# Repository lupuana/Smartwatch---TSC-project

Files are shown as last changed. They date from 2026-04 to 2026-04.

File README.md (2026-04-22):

# Smartwatch — TSC Project

> A custom-designed smartwatch based on the **Nordic nRF52840** SoC, featuring an e-paper display interface, haptic feedback, accelerometer-based motion sensing, LiPo battery management, and Bluetooth Low Energy connectivity. The PCB measures **46 × 35 mm** with rounded corners and is designed to fit inside a 3D-printed enclosure.

---

## Table of Contents

1. [Block Diagram](#block-diagram)
2. [Bill of Materials (BOM)](#bill-of-materials-bom)
3. [Hardware Description](#hardware-description)
4. [nRF52840 Pin Assignments](#nrf52840-pin-assignments)
5. [PCB Images](#pcb-images)
6. [Mechanical / Enclosure](#mechanical--enclosure)
7. [Design Notes](#design-notes)

---

## Block Diagram

```
                          ┌───────────────────────────────────────────────────────────────────┐
                          │                        nRF52840 (U1)                              │
                          │   ARM Cortex-M4F @ 64 MHz · 1 MB Flash · 256 KB RAM · BLE 5.0   │
                          └──┬──────────┬──────────┬──────────┬──────────┬──────────┬────────┘
                             │          │          │          │          │          │
                    SPI Bus  │   I2C Bus│  I2C Bus │  GPIO    │  SWD     │  GPIO    │  GPIO
                             │          │          │          │          │          │
               ┌─────────────▼──┐  ┌───▼────┐ ┌──▼──────┐  │   ┌──────▼──────┐  ┌▼───────┐
               │  E-Paper (EPD) │  │ BMA423 │ │DRV2605  │  │   │ TC2030-IDC  │  │ 3× SW  │
               │  24-pin FPC    │  │ Accel. │ │ Haptic  │  │   │ SWD Debug   │  │(UP/DN/ │
               │  (J1 Molex)    │  │ (IC3)  │ │ Driver  │  │   │ Connector   │  │  ENT)  │
               └────────────────┘  └────────┘ │ (IC2)   │  │   └─────────────┘  └────────┘
                                              └─────────┘  │
                                                           │
                          ┌────────────────────────────────┼──────────────────────────────────┐
                          │              Power System       │                                  │
                          │                                 │                                  │
               ┌──────────▼──┐   ┌──────────┐   ┌────────▼──────┐   ┌──────────────────┐   │
               │ USB Type-C  │   │BQ25180   │   │  MAX17048     │   │   RT6160AWSC     │   │
               │  (J4)       ├──►│ LiPo     │   │  Fuel Gauge   │   │  Buck-Boost Reg. │   │
               │ + ESD D3    │   │ Charger  │   │  (U3) I2C     │   │  (IC9) I2C       │   │
               └─────────────┘   │ (IC1)    │   └───────────────┘   └──────────────────┘   │
                                 └────┬─────┘                                                │
                                      │ VBAT                                                 │
                                 ┌────▼─────┐                                                │
                                 │  LiPo    │                                                │
                                 │ Battery  │                                                │
                                 │ (J3 pad) │                                                │
                                 └──────────┘                                                │
                                                                                             │
               ┌──────────────────────────────────────────────────────────────────┐          │
               │                    RF Front-End                                   │          │
               │  32 MHz XTAL (X1) · 32.768 kHz XTAL (X2) · ANT1 2.45 GHz       │◄─────────┘
               │  Matching network: L1 3.9 nH · L2 10 µH · L3 15 nH             │
               └──────────────────────────────────────────────────────────────────┘
```

---

## Bill of Materials (BOM)

> Procurement links point to **JLCPCB Parts** where available; datasheets linked to official manufacturer sources.

| Ref(s) | Qty | Value / Part | Description | Package | JLCPCB / Buy Link | Datasheet |
|---|---|---|---|---|---|---|
| U1 | 1 | NRF52840-QIAA | Nordic nRF52840 SoC — main MCU, BLE 5.0, ARM Cortex-M4F | AQFN-73 (aQFN50) | [JLCPCB C190794](https://jlcpcb.com/partdetail/NordicSemiconductor-NRF52840_QIAA/C190794) | [Datasheet](https://infocenter.nordicsemi.com/pdf/nRF52840_PS_v1.7.pdf) |
| IC1 | 1 | BQ25180YBGR | 1-cell LiPo charger, I²C programmable, 1 A | 8-DSBGA (1.6×1.1 mm) | [JLCPCB C2828062](https://jlcpcb.com/partdetail/TexasInstruments-BQ25180YBGR/C2828062) | [Datasheet](https://www.ti.com/lit/ds/symlink/bq25180.pdf) |
| IC2 | 1 | DRV2605YZFR | Haptic driver for ERM/LRA motors, I²C, built-in waveform library | 9-BGA (1.44×1.44 mm) | [JLCPCB C529659](https://jlcpcb.com/partdetail/TexasInstruments-DRV2605YZFR/C529659) | [Datasheet](https://www.ti.com/lit/ds/symlink/drv2605.pdf) |
| IC3 | 1 | BMA423 | Triaxial 12-bit accelerometer, step counter, I²C/SPI | LGA-12 (2×2 mm) | [JLCPCB C332973](https://jlcpcb.com/partdetail/BoschSensortec-BMA423/C332973) | [Datasheet](https://www.bosch-sensortec.com/media/boschsensortec/downloads/datasheets/bst-bma423-ds000.pdf) |
| IC9 | 1 | RT6160AWSC | Buck-boost DC-DC converter, I²C, 15-pin WL-CSP | BGA-15 (1.4×2.3 mm) | [JLCPCB C2834980](https://jlcpcb.com/partdetail/Richtek-RT6160AWSC/C2834980) | [Datasheet](https://www.richtek.com/assets/product_file/RT6160A/DS6160A-00.pdf) |
| U3 | 1 | MAX17048G+T10 | 1-cell/2-cell LiPo fuel gauge, I²C ModelGauge | TDFN-8 (2×2 mm) | [JLCPCB C368489](https://jlcpcb.com/partdetail/MaximIntegrated-MAX17048G_T10/C368489) | [Datasheet](https://www.analog.com/media/en/technical-documentation/data-sheets/MAX17048-MAX17049.pdf) |
| J1 | 1 | 503480-2400 | Molex 0.5 mm FPC/FFC 24-circuit RA SMT dual-contact connector (EPD) | — | [Mouser 538-503480-2400](https://www.mouser.com/ProductDetail/Molex/503480-2400) | [Datasheet](https://www.molex.com/en-us/products/part-detail/5034802400) |
| J2 | 1 | TC2030-IDC | Tag-Connect 6-pin SWD programming/debug header (no-drill) | TC2030IDC | [Tag-Connect](https://www.tag-connect.com/product/tc2030-idc-nl) | [Info](https://www.tag-connect.com/wp-content/uploads/bsk-pdf-manager/TC2030-IDC-NL_Datasheet_8.pdf) |
| J4 | 1 | KH-TYPE-C-16P | USB Type-C 16-pin SMT receptacle | — | [LCSC C2832](https://www.lcsc.com/product-detail/USB-Connectors_Kinghelm-KH-TYPE-C-16P_C2832.html) | [Datasheet](https://www.kinghelm.com.cn/product/kh-type-c-16p.html) |
| ANT1 | 1 | 2450AT18B100E | 2.45 GHz chip antenna for BLE | 3216 (1.4 mm H) | [JLCPCB C341461](https://jlcpcb.com/partdetail/JohansonTechnology-2450AT18B100E/C341461) | [Datasheet](https://www.johansontechnology.com/datasheets/2450AT18B100E/2450AT18B100E.pdf) |
| D3 | 1 | USBLC6-2SC6Y | USB ESD protection TVS diode array | SOT-23-6 | [JLCPCB C2687116](https://jlcpcb.com/partdetail/STMicroelectronics-USBLC6_2SC6Y/C2687116) | [Datasheet](https://www.st.com/resource/en/datasheet/usblc6-2.pdf) |
| D2, D4, D5 | 3 | MBR0530 | Schottky diode, 30 V / 500 mA | SOD-123 | [JLCPCB C424037](https://jlcpcb.com/partdetail/OnSemiconductor-MBR0530/C424037) | [Datasheet](https://www.onsemi.com/pdf/datasheet/mbr0530-d.pdf) |
| Q3 | 1 | SI1308EDL-T1-GE3 | N-channel MOSFET, 30 V / 1.5 A | SC-70 (SOT-323) | [JLCPCB C145826](https://jlcpcb.com/partdetail/VishayIntertech-Si1308EDL_T1_GE3/C145826) | [Datasheet](https://www.vishay.com/docs/63533/si1308edl.pdf) |
| DMG2305UX-7 | 1 | DMG2305UX-7 | P-channel MOSFET, 20 V / 4.2 A | SOT-23 | [JLCPCB C145702](https://jlcpcb.com/partdetail/Diodes-DMG2305UX7/C145702) | [Datasheet](https://www.diodes.com/assets/Datasheets/DMG2305UX.pdf) |
| SW_UP, SW_DN, SW_ENT | 3 | EVP-AKE31A | Panasonic SMD tactile push-button | — | [Digi-Key P123437TR-ND](https://www.digikey.com/en/products/detail/panasonic-electronic-components/EVP-AKE31A/3071225) | [Datasheet](https://industrial.panasonic.com/cdbs/www-data/pdf/ATV0000/ATV0000CE22.pdf) |
| X1 | 1 | 32 MHz crystal | RF clock for nRF52840 BLE | 2016 (2.0×1.6 mm) | [JLCPCB C9003](https://jlcpcb.com/partdetail/9003-CX2016DB32000D0GEJCC/C9003) | [Nordic recommended crystals](https://infocenter.nordicsemi.com/topic/ps_nrf52840/chapters/radio/doc/radio.html) |
| X2 | 1 | 32.768 kHz crystal | RTC/low-power clock | 3215 (3.2×1.5 mm) | [JLCPCB C32346](https://jlcpcb.com/partdetail/Hosonic-E3SB32E002400TR/C32346) | [Nordic RTC guidance](https://infocenter.nordicsemi.com/topic/ps_nrf52840/chapters/clock/doc/clock.html) |
| L1 | 1 | 3.9 nH inductor | RF matching, 0402 | 0402 | [JLCPCB C70268](https://jlcpcb.com/partdetail/70268-CL05NPC3N9BANC/C70268) | — |
| L2 | 1 | 10 µH inductor | BLE DC supply filter, 0402 | 0402 | [JLCPCB C1046](https://jlcpcb.com/partdetail/1046-CL31A226KAHNNNE/C1046) | — |
| L3 | 1 | 15 nH inductor | RF matching, 0402 | 0402 | [JLCPCB C70268](https://jlcpcb.com/partdetail/70268-CL05NPC3N9BANC/C70268) | — |
| L5 | 1 | 744043680 (68 µH) | Würth EP power inductor for buck-boost | 4828 (WE-TPC) | [JLCPCB C408386](https://jlcpcb.com/partdetail/WurthElektronik-744043680/C408386) | [Datasheet](https://www.we-online.com/en/components/products/WE-TPC#744043680) |
| L7 | 1 | FTC252012SR47MBCA | 0.47 µH power inductor for battery charger | MLP2016 (2×1.6 mm) | [JLCPCB C5832368](https://jlcpcb.com/partdetail/6763488-FTC252012SR47MBCA/C5832368) | [Datasheet](https://product.tdk.com/en/search/inductor/inductor/smd/info?part_no=FTC252012SR47MBCA) |
| C1–C43, EPD_Cx | ~50 | Various caps | Decoupling / bypass / filter (1 pF – 22 µF) | 0201, 0402 | JLCPCB standard passives | — |
| R1–R18, R_* | ~20 | Various resistors | Pull-ups, current-sense, type-select (0 Ω – 10 kΩ) | 0201 | JLCPCB standard passives | — |
| SJ1 | 1 | Solder jumper | EPD power rail selection | — | — | — |
| TP_* | 14 | Test pads | GND, 3V3, VBAT, SDA, SCL, SWDCLK, SWDIO, SWO, RESET, etc. | TP20R | — | — |

---

## Hardware Description

### 1. Microcontroller — Nordic nRF52840 (U1)

The nRF52840 is the heart of the project. It is an ARM Cortex-M4F SoC running at up to 64 MHz, with 1 MB of internal Flash, 256 KB RAM, and an integrated BLE 5.0 + 802.15.4 radio. It was chosen for its best-in-class sleep current (~2 µA in System OFF with RAM retention), its rich peripheral set (SPI, I²C, UART, USB, SWD), and its support for the Nordic SDK / Zephyr RTOS.

The chip is clocked by two external crystals: a 32 MHz crystal (X1) used as the main RF clock, and a 32.768 kHz crystal (X2) used by the RTC for low-power timekeeping. The RF matching network (L1 3.9 nH, L3 15 nH, and associated capacitors) connects the chip's antenna output to the chip antenna ANT1.

### 2. E-Paper Display Interface

The e-paper display (EPD) connects through a **Molex 503480-2400** 24-pin 0.5 mm pitch FPC right-angle connector (J1). The display is driven over **SPI** from the nRF52840. A dedicated group of capacitors (EPD_C1–EPD_C12, all 1 µF/50 V in 0402) and a filter capacitor (EPD_C5, 100 nF/50 V) provide local bypass for the EPD power rails. A solder jumper (SJ1) allows selecting the EPD supply source. The P-channel MOSFET (DMG2305UX-7) acts as a load switch to cut EPD power when the display is not being updated, minimising average current draw.

> **Note:** The display module itself is not included in this design iteration — the FPC connector and power circuitry are present and ready for integration.

### 3. Power Management

Power management is implemented with a three-chip solution:

**BQ25180YBGR (IC1) — LiPo Charger.** This Texas Instruments single-cell charger accepts 5 V from the USB Type-C port and charges a LiPo battery at up to 1 A. Charge current is configured via a current-sense resistor (R1_EP_DR, 0.47 Ω). The charger communicates with the nRF52840 over I²C for status reporting and charge parameter programming. An inductor L7 (0.47 µH) is used in the switch-mode charging path. Schottky diodes D2, D4, D5 (MBR0530) protect against reverse current conditions.

**MAX17048G+T10 (U3) — Fuel Gauge.** This Analog Devices ModelGauge IC measures the battery state-of-charge using a voltage-based algorithm, eliminating the need for a series current-sense resistor. It communicates over I²C and draws only 3 µA during normal operation, making it suitable for always-on battery monitoring.

**RT6160AWSC (IC9) — Buck-Boost Regulator.** This Richtek I²C-programmable buck-boost converter maintains a stable 3.3 V output rail (VREG) from the LiPo battery voltage, which can range from ~3.0 V (discharged) to 4.2 V (fully charged). The output voltage is dynamically adjustable via I²C, and the converter supports up to ~600 mA output current. The large 68 µH inductor L5 (Würth 744043680) is used in the power conversion path.

**USB Protection.** The USB Type-C port (J4) is protected by a USBLC6-2SC6Y (D3) ESD TVS diode array in SOT-23-6, clamping transients to a safe level before they reach the nRF52840's USB pins. The USB CC lines carry 5.1 kΩ resistors (R1_USB, R2_USB) for USB-C sink identification.

### 4. Accelerometer — BMA423 (IC3)

The Bosch BMA423 is a triaxial 12-bit accelerometer with hardware step counting, activity recognition (walk, run, still), and wrist-tilt gesture detection — all computed on-chip, so the main MCU can remain in deep sleep. It connects to the nRF52840 over **I²C**. Pull-up resistors (R5, R7 — 10 kΩ each) are placed on the SDA and SCL lines. The device draws only 14 µA in low-power mode at 25 Hz ODR.

### 5. Haptic Driver — DRV2605YZFR (IC2)

The Texas Instruments DRV2605 drives an ERM (eccentric rotating mass) or LRA (linear resonant actuator) vibration motor. It contains a library of 123 pre-programmed haptic waveforms accessible over **I²C**, allowing the firmware to trigger complex tactile patterns with a single register write. Pull-up resistors R17 and R18 (3.3 kΩ each) are provided on the I²C lines shared with the haptic driver.

### 6. Navigation Buttons

Three Panasonic EVP-AKE31A SMD tactile push-buttons are placed along the bottom edge of the PCB (SW_UP, SW_DN, SW_ENT), corresponding to UP, DOWN, and ENTER/SELECT functions. Each button connects to a GPIO pin of the nRF52840 with 10 kΩ pull-up resistors (R5, R7, R8). The nRF52840's internal sense and GPIO interrupt mechanisms enable wake-from-sleep on button press.

### 7. BLE Antenna

The 2.45 GHz chip antenna 2450AT18B100E from Johanson Technology (ANT1) is a compact 3.2×1.6 mm ceramic antenna placed at the top edge of the PCB, away from ground pours to maximise radiation efficiency. The matching network (L1, L3, and associated capacitors C3, C4) is tuned for 50 Ω impedance at 2.45 GHz as recommended by the nRF52840 reference design.

### 8. Debug / Programming Interface

A Tag-Connect TC2030-IDC footprint (J2) provides a 6-pin no-drill SWD debug interface, exposing SWDCLK, SWDIO, SWO, RESET, GND, and VCC. Dedicated test points (TP_SWDCLK, TP_SWDIO, TP_SWO, TP_RESET) are accessible on the PCB for bench probing.

### 9. Power Consumption Estimates

| Mode | Dominant Consumer | Estimated Current |
|---|---|---|
| BLE advertising (1 Hz) | nRF52840 radio | ~20 µA average |
| BLE connected (15 ms CI) | nRF52840 radio | ~5–8 mA peak, ~500 µA avg |
| EPD full refresh | EPD + nRF52840 | ~20 mA peak, ~2 s |
| Accelerometer step count only | BMA423 | ~14 µA |
| Haptic pulse (100 ms) | DRV2605 + motor | ~50–120 mA peak |
| System OFF (deep sleep) | nRF52840, fuel gauge | ~5–8 µA |

With a typical 150–300 mAh LiPo battery and BLE advertising once per second, an estimated **5–10 days** of battery life is achievable when the EPD is updated only a few times per day.

---

## nRF52840 Pin Assignments

| nRF52840 Pin | Signal Name | Connected To | Interface | Notes |
|---|---|---|---|---|
| P0.02 | AREF | ADC reference | Analog | Optional ADC reference |
| P0.04 / AIN2 | BATTERY_ADC | VBAT resistor divider | ADC | Battery voltage sense backup |
| P0.06 | UART_TX | Debug UART | UART | Optional logging |
| P0.08 | UART_RX | Debug UART | UART | Optional logging |
| P0.11 | SW_UP | SW_UP button | GPIO IN | Active-low, pull-up 10 kΩ |
| P0.12 | SW_DN | SW_DN button | GPIO IN | Active-low, pull-up 10 kΩ |
| P0.13 | SW_ENT | SW_ENT button | GPIO IN | Active-low, pull-up 10 kΩ |
| P0.14 / SDA | I2C_SDA | BMA423, DRV2605, BQ25180, MAX17048, RT6160 | I²C | 10 kΩ pull-up to 3V3 |
| P0.15 / SCL | I2C_SCL | BMA423, DRV2605, BQ25180, MAX17048, RT6160 | I²C | 10 kΩ pull-up to 3V3 |
| P0.16 | EPD_MOSI | EPD SPI data | SPI | — |
| P0.17 | EPD_SCK | EPD SPI clock | SPI | — |
| P0.18 / RESET | nRESET | TP_RESET, TC2030 | Reset | Active-low hardware reset |
| P0.19 | EPD_CS | EPD chip select | SPI / GPIO | Active-low |
| P0.20 | EPD_DC | EPD data/command select | GPIO | — |
| P0.21 | EPD_RST | EPD hardware reset | GPIO | Active-low |
| P0.22 | EPD_BUSY | EPD busy signal | GPIO IN | Input, pulled low by EPD |
| P0.23 | EPD_PWR_EN | DMG2305UX-7 gate | GPIO | Controls EPD power switch |
| P0.26 | VIB_EN | DRV2605 IN/TRIG | GPIO | Haptic trigger |
| P0.31 / AIN7 | BAT_SENSE | MAX17048 / VBAT | ADC / I²C | Fuel gauge interrupt line |
| P1.00 | SWO | TC2030-IDC pin 6 | SWD | Trace output |
| SWDIO | SWDIO | TC2030-IDC pin 2, TP_SWDIO | SWD | — |
| SWDCLK | SWDCLK | TC2030-IDC pin 4, TP_SWDCLK | SWD | — |
| GND | GND | Common ground, TP_GND | — | Multiple ground test points |
| VDD | 3V3 (from RT6160) | Decoupling caps C5–C19 etc. | Power | Per Nordic reference layout |
| VDDMAIN | 3V3 | Bulk decoupling | Power | — |
| XC1 / XC2 | 32 MHz XTAL | X1 | XTAL | Pins per nRF52840 datasheet |
| XL1 / XL2 | 32.768 kHz XTAL | X2 | XTAL | Pins per nRF52840 datasheet |
| ANT | RF output | L1 → ANT1 | RF | Via matching network |

---

## PCB Images

### 2D Layout — Top Layer

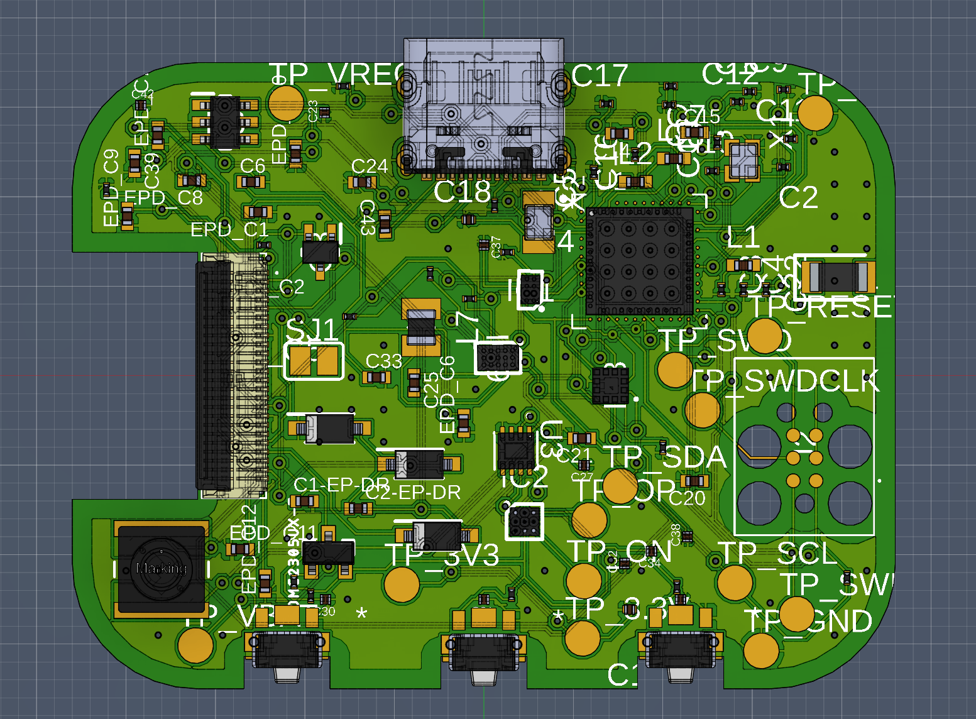
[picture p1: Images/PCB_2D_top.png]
PCB Top Layer


### 2D Layout — Bottom Layer

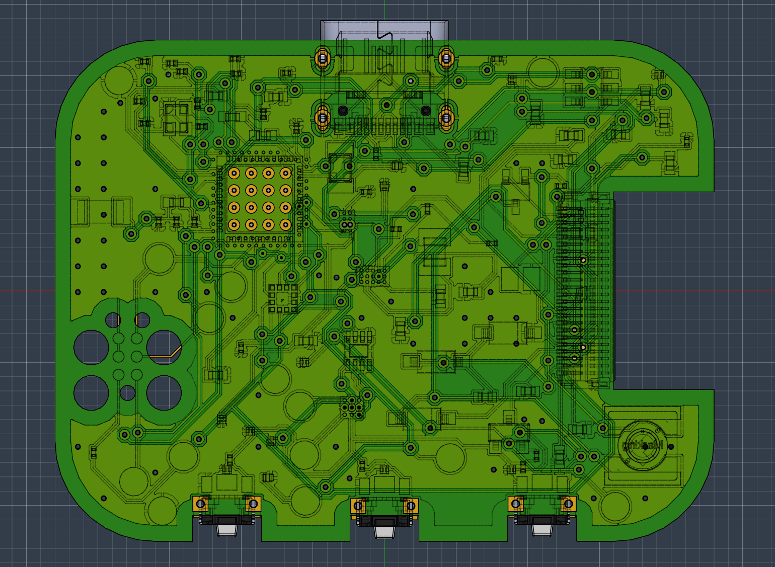
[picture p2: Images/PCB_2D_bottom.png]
PCB Bottom Layer


### 2D Layout — Combined (Top + Bottom)

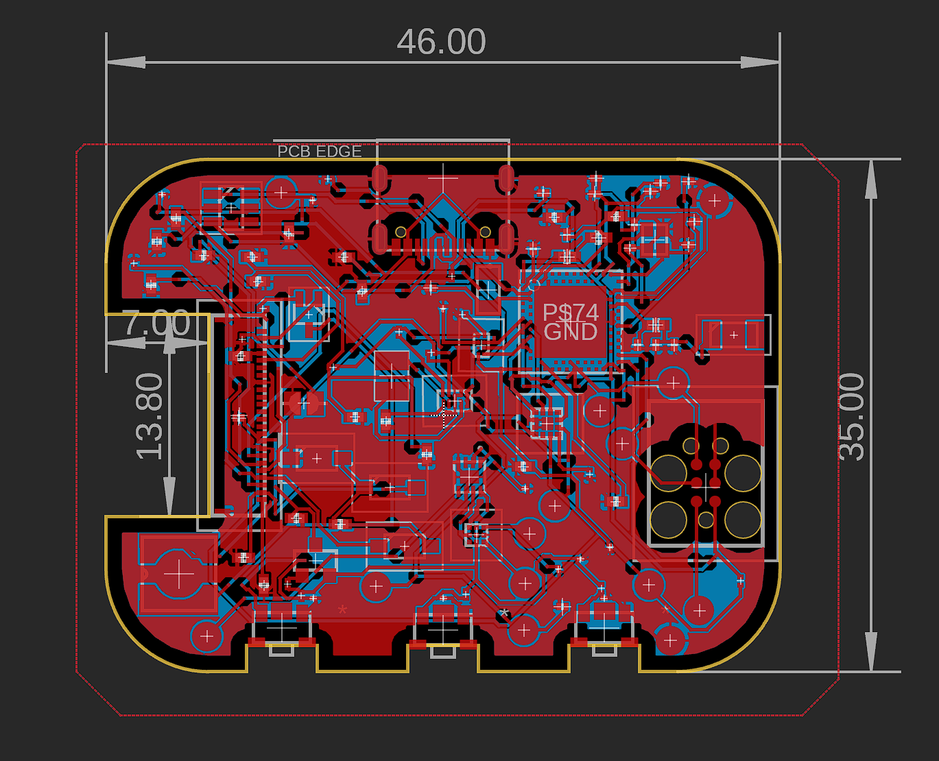
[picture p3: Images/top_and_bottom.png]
PCB Top and Bottom


### 3D Render — Top

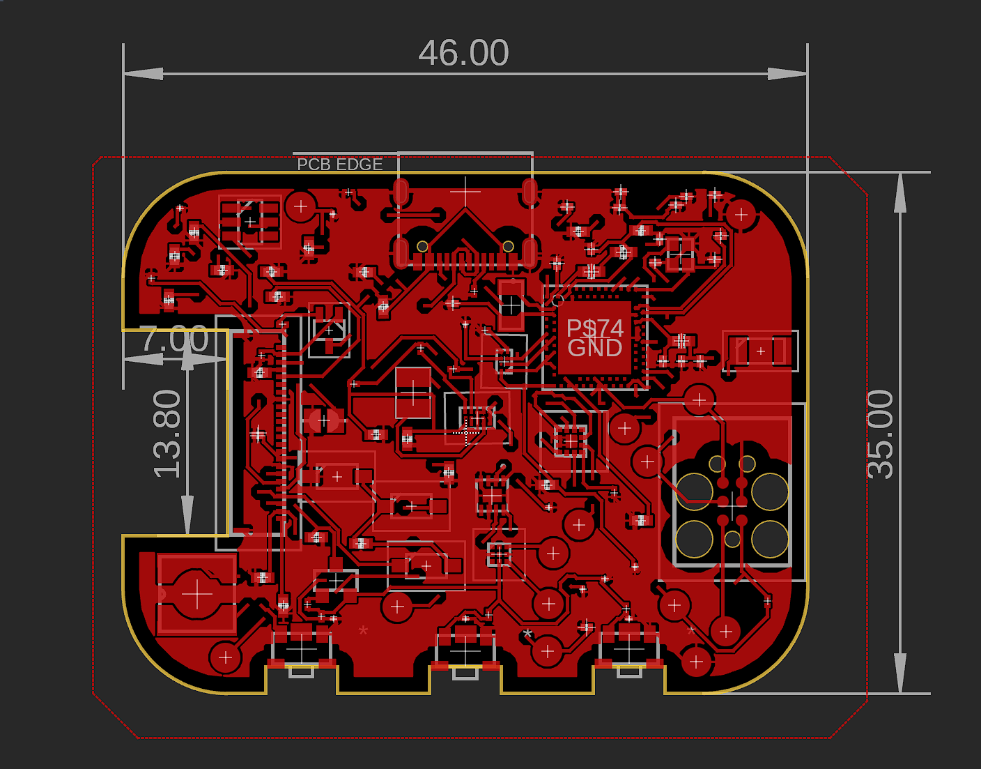
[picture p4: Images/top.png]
3D Render Top


### 3D Render — Bottom

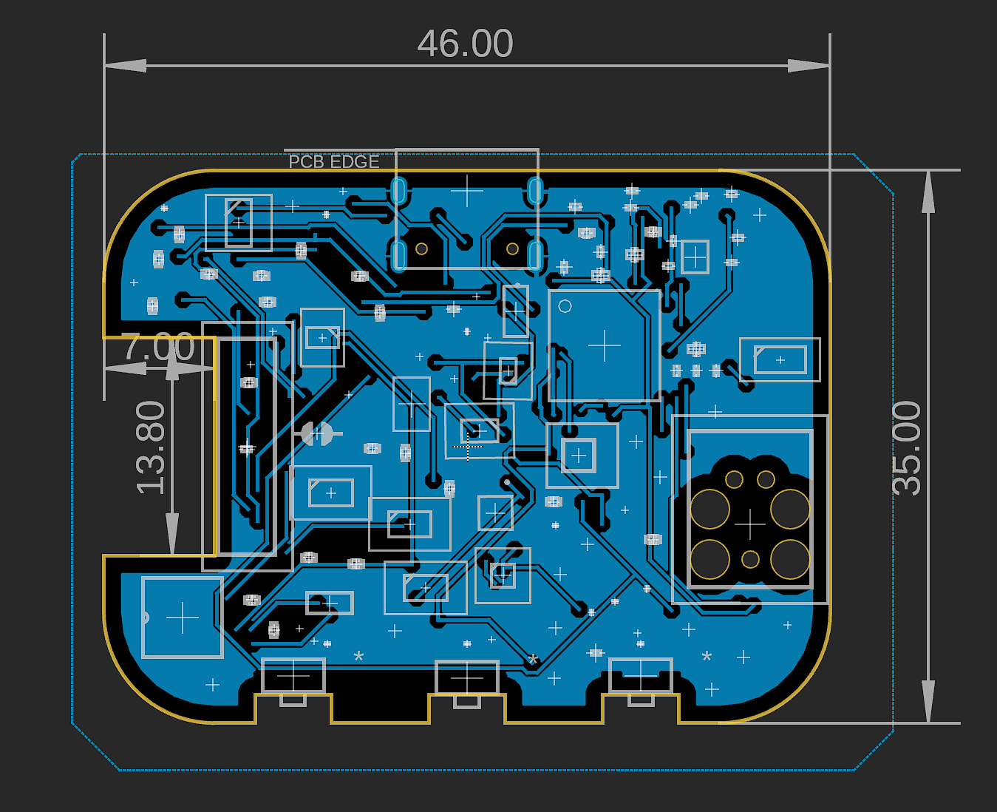
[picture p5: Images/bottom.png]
3D Render Bottom


### PCB Dimensions

The PCB is **46.00 mm × 35.00 mm** with a cut-out on the left side (7.00 mm wide × 13.80 mm tall) accommodating the LiPo battery connector tab and the FPC connector J1 for the e-paper display.

---

## Mechanical / Enclosure

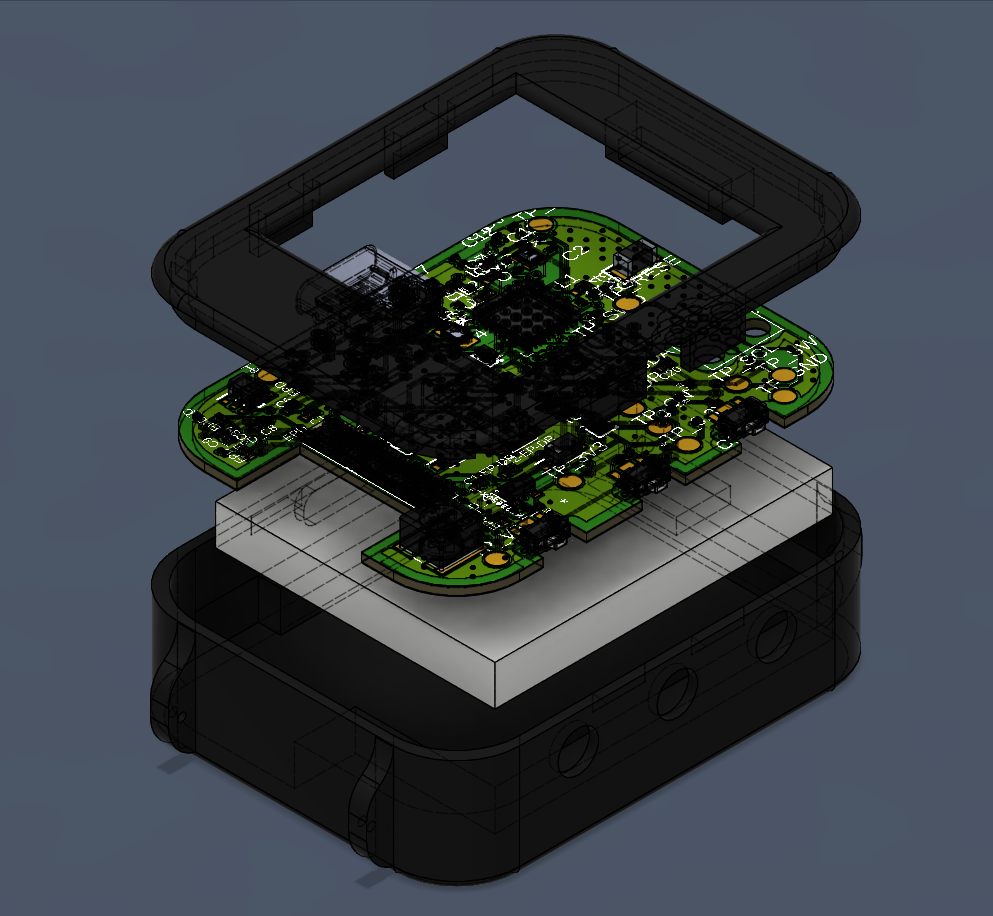
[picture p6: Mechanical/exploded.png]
Exploded View


The enclosure consists of three layers visible in the exploded view:

1. **Top bezel** — a rectangular frame (black) with a rectangular opening for the e-paper display window.
2. **PCB assembly** — the 46×35 mm PCB sits in the middle, with the USB-C port and buttons accessible through slots/holes in the case sides.
3. **Battery + bottom shell** — the LiPo battery sits below the PCB in the bottom half of the case. The bottom shell is rounded and ergonomic, designed for wrist wear.

The 3D model is provided in Fusion 360 format (`.f3z`) in the `Mechanical/` folder.

---

## Design Notes

- **No display in current iteration:** The e-paper display and its FPC cable are intentionally omitted from the current hardware build. All EPD power and SPI signals are routed and terminated at the Molex FPC connector, ready for the next revision.
- **I²C bus sharing:** BMA423, DRV2605, BQ25180, MAX17048, and RT6160 all share a single I²C bus. Each device has a unique 7-bit address, and the bus pull-ups (10 kΩ) are placed once on the PCB. Bus speed is 400 kHz (Fast Mode).
- **EPD power isolation:** The DMG2305UX-7 P-MOSFET switches the EPD supply rail off when not refreshing. This prevents the display from drawing quiescent current during sleep, which can be 50–200 µA on typical e-paper modules.
- **USB-C:** Only USB 2.0 full-speed is implemented (nRF52840 native USB), sufficient for DFU firmware updates and serial logging. The CC resistors (5.1 kΩ) configure the device as a standard 5V/500 mA sink.
- **Gerber files** for manufacturing are located in `Manufacturing/gerbers.zip`.
- **License:** MIT — see `LICENSE` for details.

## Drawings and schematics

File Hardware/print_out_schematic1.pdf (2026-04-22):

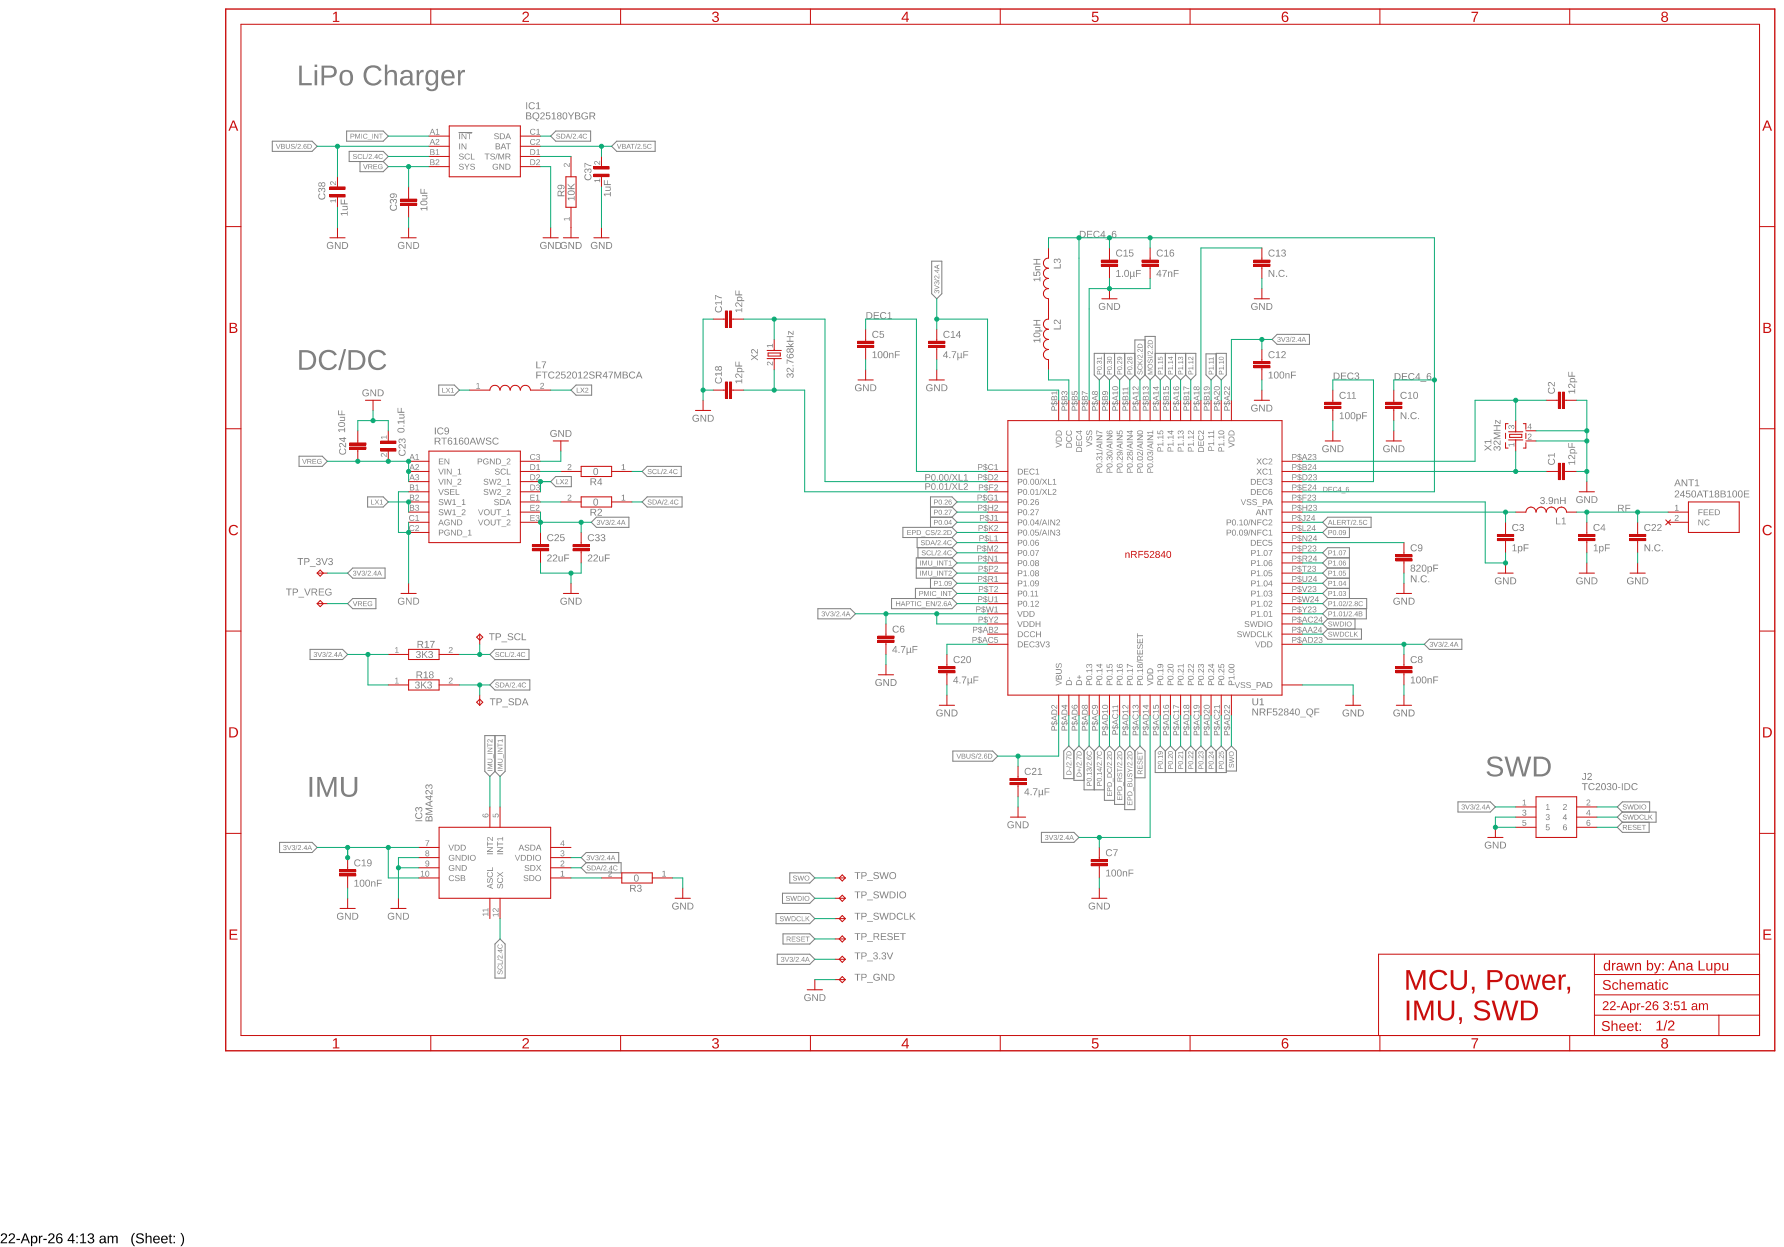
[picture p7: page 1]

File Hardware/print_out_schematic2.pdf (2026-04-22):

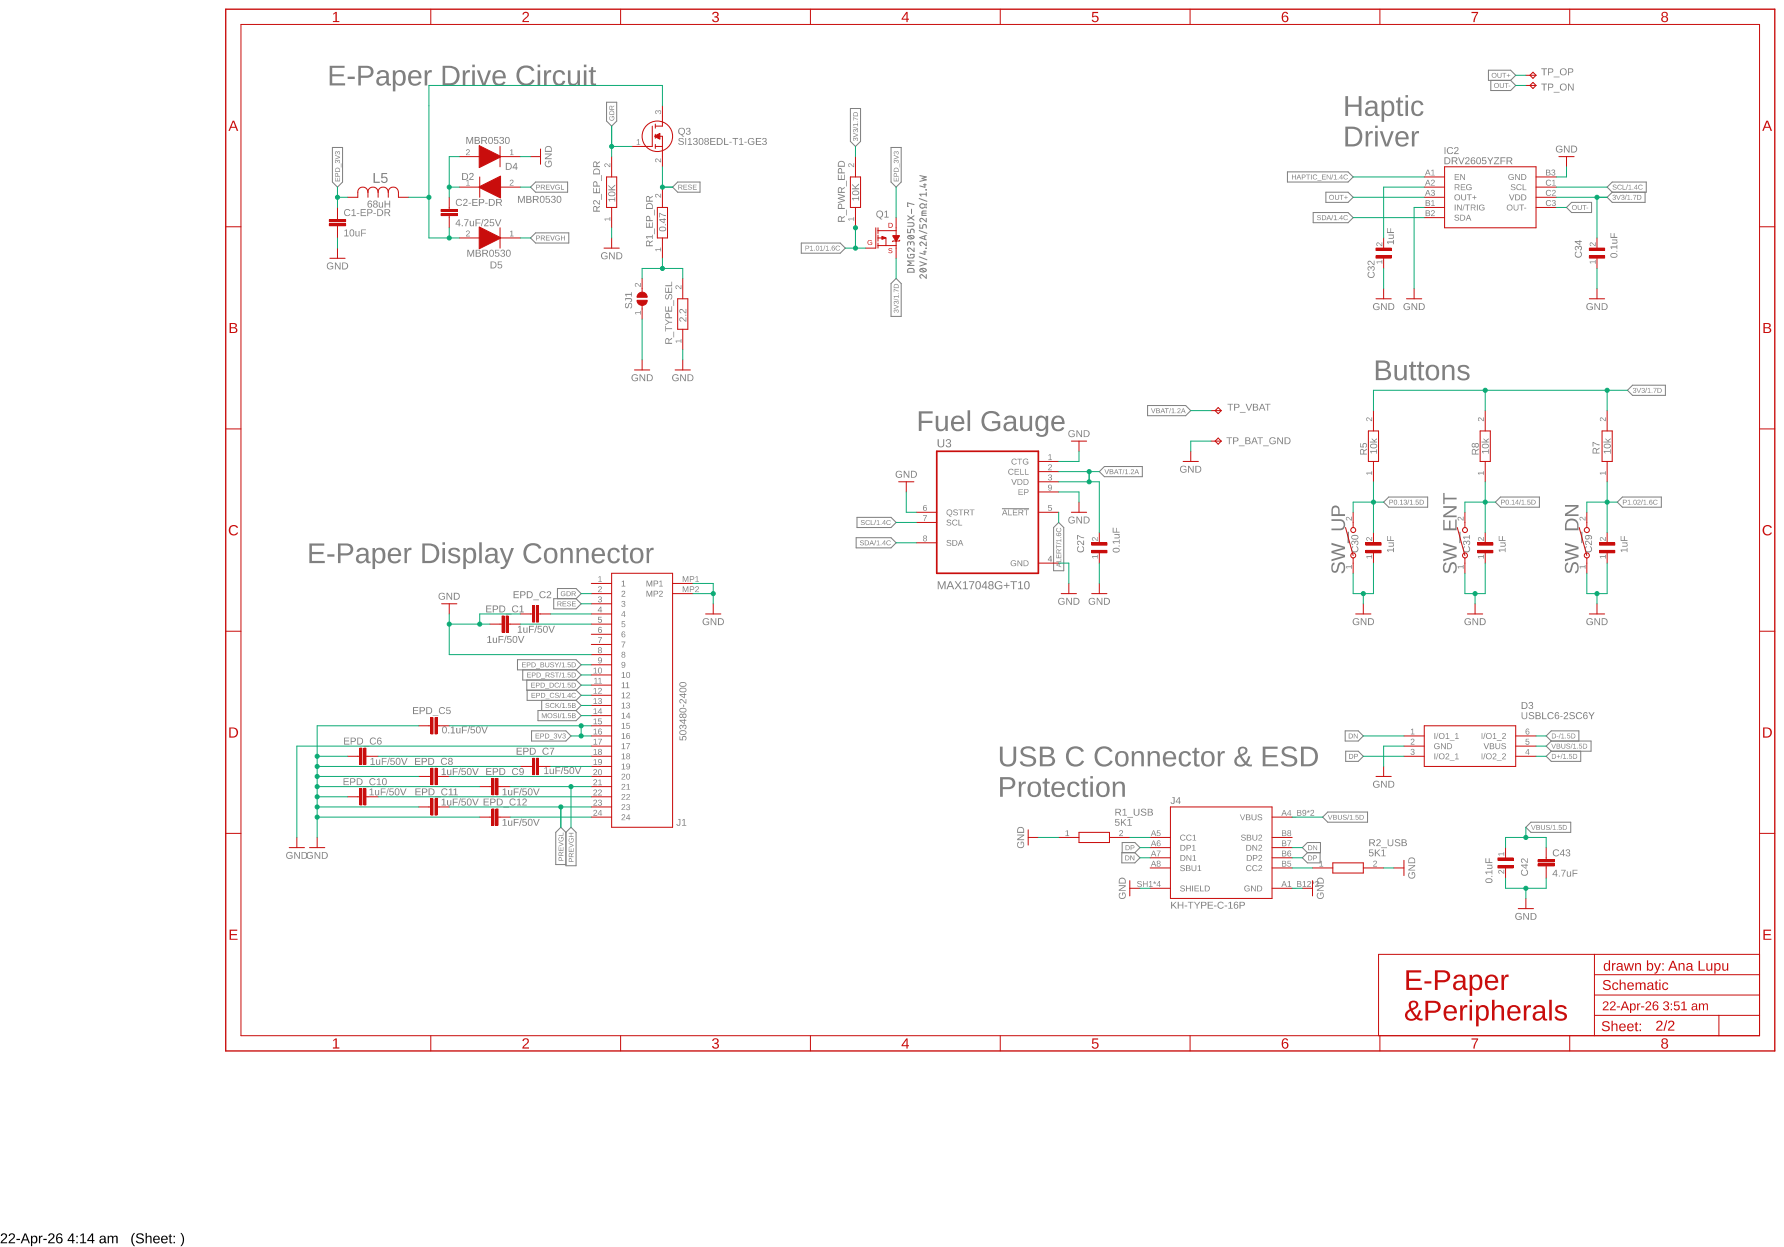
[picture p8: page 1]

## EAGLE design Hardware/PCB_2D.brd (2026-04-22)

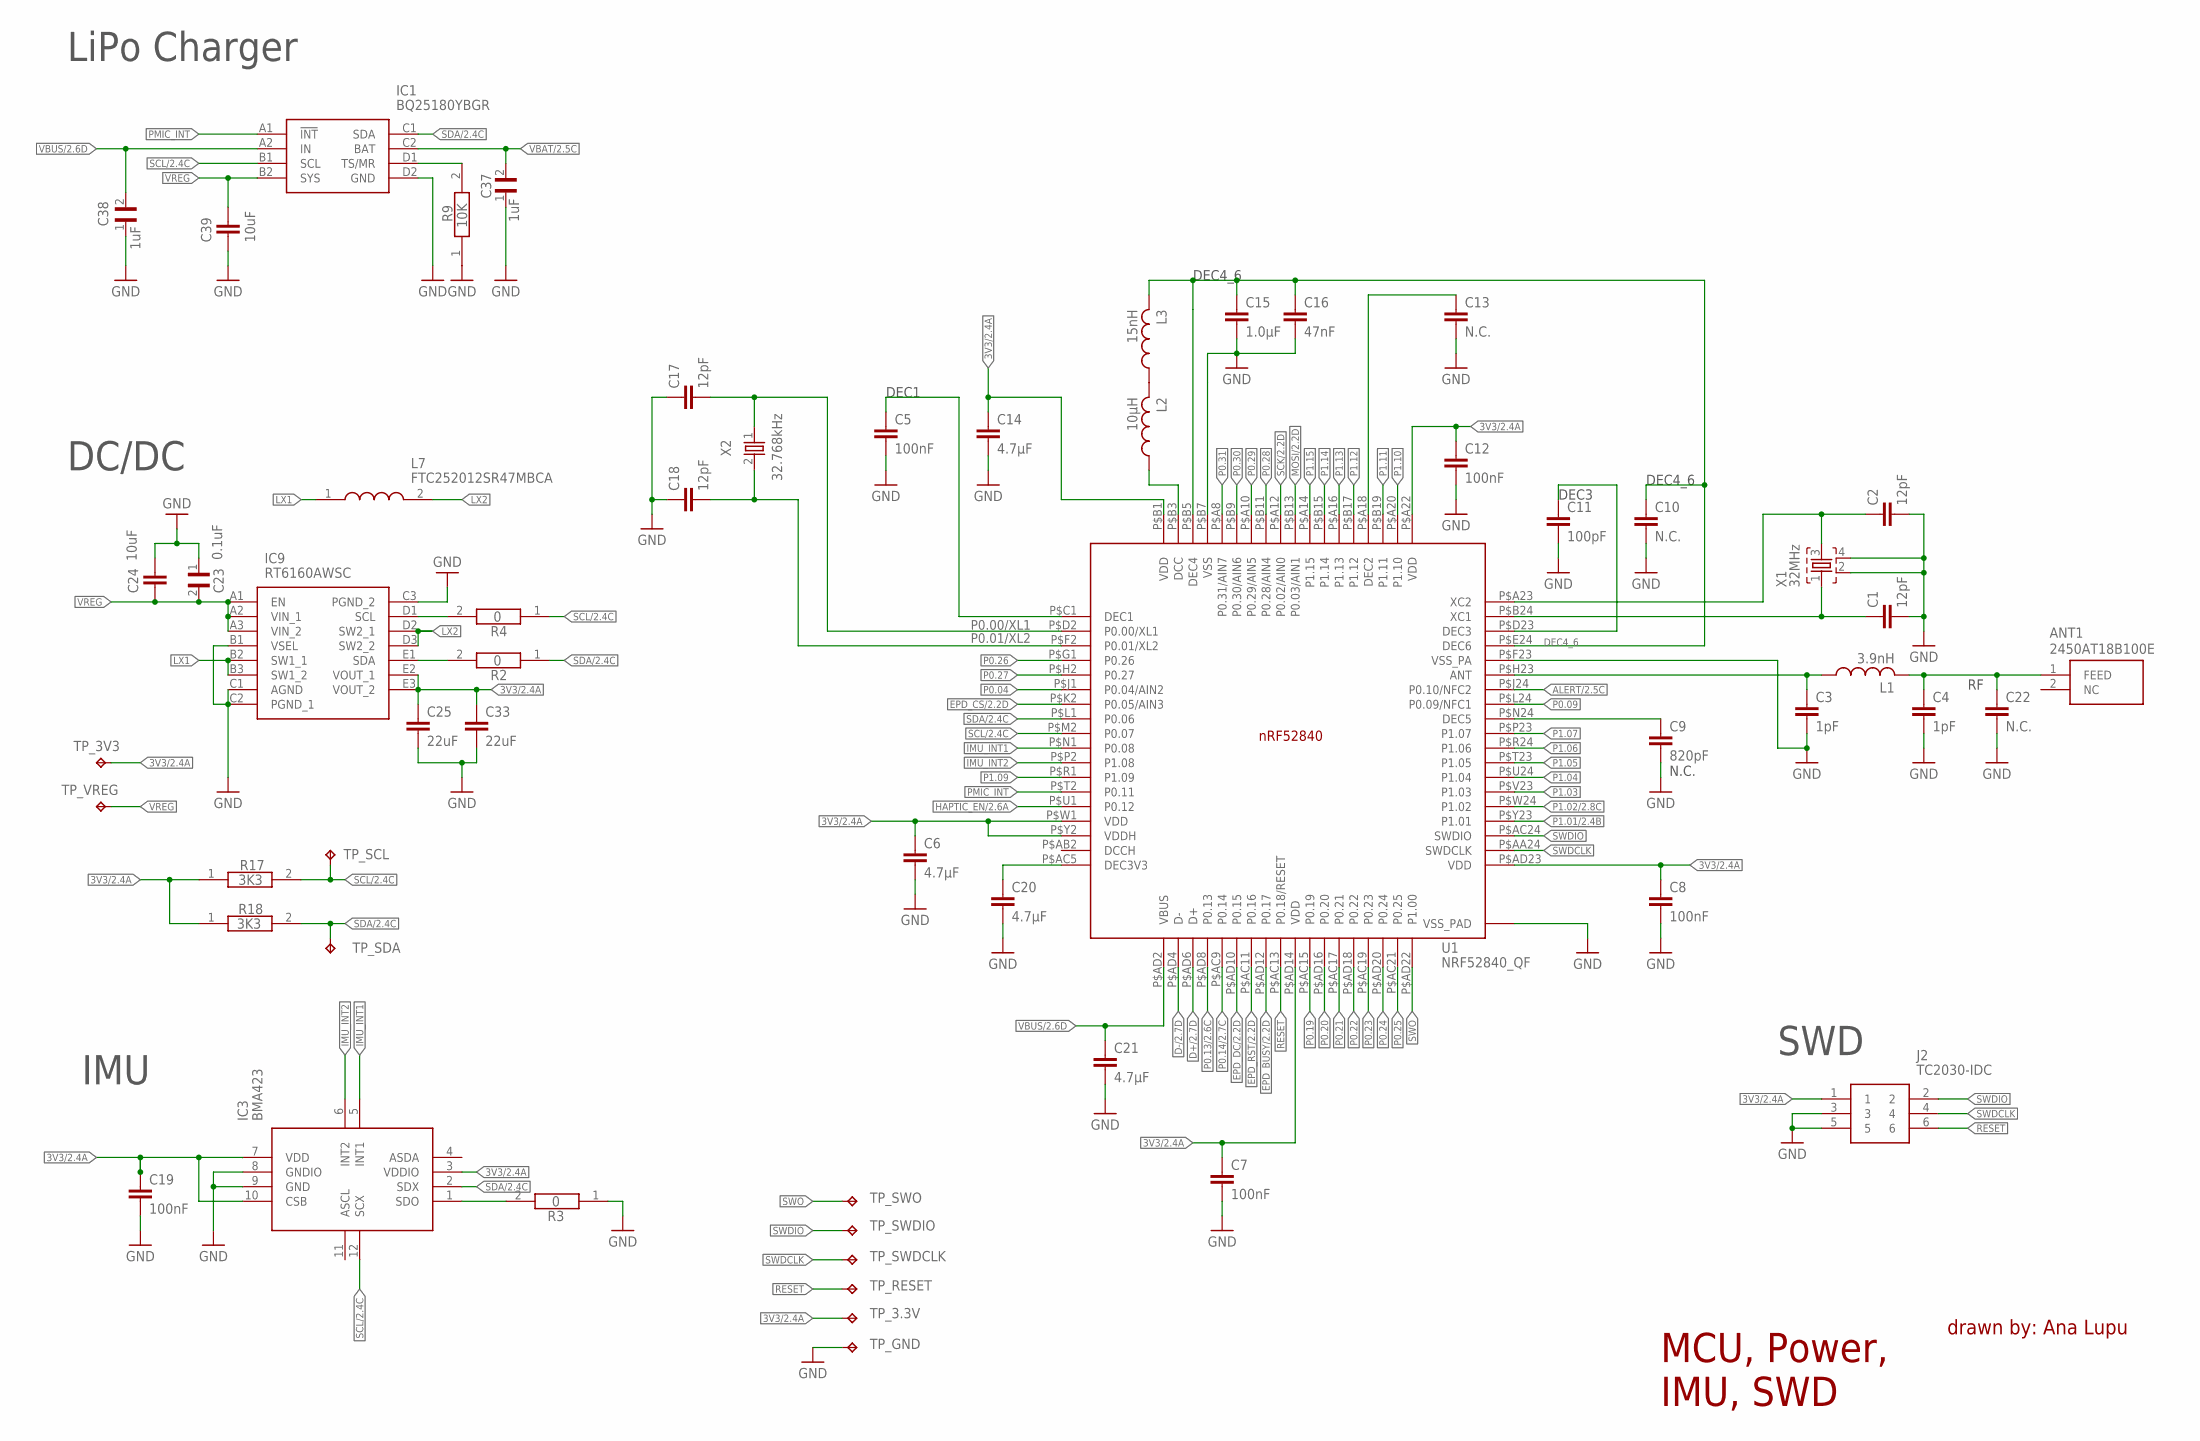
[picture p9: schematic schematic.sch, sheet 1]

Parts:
ANT1: 2450AT18B100E; 2450AT18B100E_ANTC3216X140N
C1, C2, C17, C18: 12pF; NORDIC_NRF_3_RESC0201_L
C3, C4: 1pF; NORDIC_NRF_3_RESC0201_L
C5, C7, C8, C12, C19: 100nF; NORDIC_NRF_3_RESC0201_L
C6, C14, C20, C21: 4.7µF; PERFECT_0402_0402
C9: 820pF; NORDIC_NRF_3_RESC0201_L
C10, C13, C22: N.C.; NORDIC_NRF_3_RESC0201_L
C11: 100pF; NORDIC_NRF_3_RESC0201_L
C15: 1.0µF; PERFECT_0402_0402
C16: 47nF; NORDIC_NRF_3_RESC0201_L
C23: 0.1uF; GRM011R60J152KE01L_2_CAPC0201X13N
C24, C39: 10uF; PERFECT_0402_0402
C25, C33: 22uF; PERFECT_0402_0402
C37, C38: 1uF; GRM011R60J152KE01L_2_CAPC0201X13N
IC1: BQ25180YBGR; BQ25180YBGR_BGA8C40P2X4_100X155X50
IC3: BMA423; BMA423_BMA423
IC9: RT6160AWSC; RT6160AWSC_BGA15C40P3X5_140X230X60
J2: TC2030-IDC; TC2030-IDC_TC2030IDC
L1: 3.9nH; NORDIC_NRF_2_RESC0402_M
L2: 10μH; NORDIC_NRF_2_RESC0402_M
L3: 15nH; NORDIC_NRF_2_RESC0402_M
L7: FTC252012SR47MBCA; MLP2016SR47MT0S1_INDC2016X100N
R2, R3, R4: 0; CPF0201D7K68C1_0201
R9: 10K; CPF0201D7K68C1_0201
R17, R18: 3K3; CPF0201D7K68C1_0201
TP_3.3V, TP_3V3: HECTOR_WATCH_1_TPTP20R; HECTOR_WATCH_1_TP20R
TP_GND: HECTOR_WATCH_1_TPTP20R; HECTOR_WATCH_1_TP20R
TP_RESET: HECTOR_WATCH_1_TPTP20R; HECTOR_WATCH_1_TP20R
TP_SCL: HECTOR_WATCH_1_TPTP20R; HECTOR_WATCH_1_TP20R
TP_SDA: HECTOR_WATCH_1_TPTP20R; HECTOR_WATCH_1_TP20R
TP_SWDCLK: HECTOR_WATCH_1_TPTP20R; HECTOR_WATCH_1_TP20R
TP_SWDIO: HECTOR_WATCH_1_TPTP20R; HECTOR_WATCH_1_TP20R
TP_SWO: HECTOR_WATCH_1_TPTP20R; HECTOR_WATCH_1_TP20R
TP_VREG: HECTOR_WATCH_1_TPTP20R; HECTOR_WATCH_1_TP20R
U1: NRF52840_QF; NORDIC_NRF_4_AQFN50P700X700X85_HS-74N
X1: 32MHz; NORDIC_NRF_BT-XTAL_2016_N
X2: 32.768kHz; NORDIC_NRF_1_XTAL_3215_N

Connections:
3V3/2.4A: C6.1, C7.1, C8.1, C12.1, C14.1, C19.1, C25.1, C33.1, IC3.3 (VDDIO), IC3.7 (VDD), IC3.10 (CSB), IC9.E2 (VOUT_1), IC9.E3 (VOUT_2), J2.1, R17.1, R18.1, TP_3.3V.TP, TP_3V3.TP, U1.P$A22 (VDD), U1.P$AD14 (VDD), U1.P$AD23 (VDD), U1.P$B1 (VDD), U1.P$W1 (VDD), U1.P$Y2 (VDDH)
ALERT/2.5C: U1.P$J24 (P0.10/NFC2)
D+/2.7D: U1.P$AD6 (D+)
D-/2.7D: U1.P$AD4 (D-)
DEC4_6: C10.1, C15.1, C16.1, L3.2, U1.P$B5 (DEC4), U1.P$E24 (DEC6)
EPD_BUSY/2.2D: U1.P$AD12 (P0.17)
EPD_CS/2.2D: U1.P$K2 (P0.05/AIN3)
EPD_DC/2.2D: U1.P$AD10 (P0.15)
EPD_RST/2.2D: U1.P$AC11 (P0.16)
GND: C1.2, C2.2, C3.2, C4.2, C5.2, C6.2, C7.2, C8.2, C9.2, C10.2, C11.2, C12.2, C13.2, C14.2, C15.2, C16.2, C17.1, C18.1, C19.2, C20.2, C21.2, C22.2, C23.1, C24.1, C25.2, C33.2, C37.1, C38.1, C39.2, IC1.D2 (GND), IC3.8 (GNDIO), IC3.9 (GND), IC9.B1 (VSEL), IC9.C1 (AGND), IC9.C2 (PGND_1), IC9.C3 (PGND_2), J2.3, J2.5, R3.1, R9.1, TP_GND.TP, U1.P$74 (VSS_PAD), U1.P$75 (VSS_PAD), U1.P$76 (VSS_PAD), U1.P$77 (VSS_PAD), U1.P$78 (VSS_PAD), U1.P$79 (VSS_PAD), U1.P$80 (VSS_PAD), U1.P$81 (VSS_PAD), U1.P$82 (VSS_PAD), U1.P$83 (VSS_PAD), U1.P$84 (VSS_PAD), U1.P$85 (VSS_PAD), U1.P$86 (VSS_PAD), U1.P$87 (VSS_PAD), U1.P$88 (VSS_PAD), U1.P$89 (VSS_PAD), U1.P$90 (VSS_PAD), U1.P$B7 (VSS), U1.P$F23 (VSS_PA), X1.2, X1.4; also elsewhere on the board
HAPTIC_EN/2.6A: U1.P$U1 (P0.12)
IMU_INT1: IC3.5 (INT1), U1.P$N1 (P0.08)
IMU_INT2: IC3.6 (INT2), U1.P$P2 (P1.08)
LX1: IC9.B2 (SW1_1), IC9.B3 (SW1_2), L7.1
LX2: IC9.D2 (SW2_1), IC9.D3 (SW2_2), L7.2
MOSI/2.2D: U1.P$B13 (P0.03/AIN1)
unnamed: C5.1, U1.P$C1 (DEC1)
unnamed: IC1.D1 (TS/MR), R9.2
unnamed: C20.1, U1.P$AC5 (DEC3V3)
unnamed: L2.1, U1.P$B3 (DCC)
unnamed: C1.1, U1.P$B24 (XC1), X1.1
unnamed: IC9.D1 (SCL), R4.2
unnamed: C13.1, U1.P$A18 (DEC2)
unnamed: IC9.E1 (SDA), R2.2
unnamed: L2.2, L3.1
unnamed: IC3.1 (SDO), R3.2
unnamed: C9.1, U1.P$N24 (DEC5)
unnamed: ANT1.1 (FEED), C4.1, C22.1, L1.2
unnamed: C3.1, L1.1, U1.P$H23 (ANT)
unnamed: C2.1, U1.P$A23 (XC2), X1.3
unnamed: C11.1, U1.P$D23 (DEC3)
P0.00/XL1: C17.2, U1.P$D2 (P0.00/XL1), X2.1
P0.01/XL2: C18.2, U1.P$F2 (P0.01/XL2), X2.2
P0.04: U1.P$J1 (P0.04/AIN2)
P0.09: U1.P$L24 (P0.09/NFC1)
P0.13/2.6C: U1.P$AD8 (P0.13)
P0.14/2.7C: U1.P$AC9 (P0.14)
P0.19: U1.P$AC15 (P0.19)
P0.20: U1.P$AD16 (P0.20)
P0.21: U1.P$AC17 (P0.21)
P0.22: U1.P$AD18 (P0.22)
P0.23: U1.P$AC19 (P0.23)
P0.24: U1.P$AD20 (P0.24)
P0.25: U1.P$AC21 (P0.25)
P0.26: U1.P$G1 (P0.26)
P0.27: U1.P$H2 (P0.27)
P0.28: U1.P$B11 (P0.28/AIN4)
P0.29: U1.P$A10 (P0.29/AIN5)
P0.30: U1.P$B9 (P0.30/AIN6)
P0.31: U1.P$A8 (P0.31/AIN7)
P1.01/2.4B: U1.P$Y23 (P1.01)
P1.02/2.8C: U1.P$W24 (P1.02)
P1.03: U1.P$V23 (P1.03)
P1.04: U1.P$U24 (P1.04)
P1.05: U1.P$T23 (P1.05)
P1.06: U1.P$R24 (P1.06)
P1.07: U1.P$P23 (P1.07)
P1.09: U1.P$R1 (P1.09)
P1.10: U1.P$A20 (P1.10)
P1.11: U1.P$B19 (P1.11)
P1.12: U1.P$B17 (P1.12)
P1.13: U1.P$A16 (P1.13)
P1.14: U1.P$B15 (P1.14)
P1.15: U1.P$A14 (P1.15)
PMIC_INT: IC1.A1 (!INT), U1.P$T2 (P0.11)
RESET: J2.6, TP_RESET.TP, U1.P$AC13 (P0.18/RESET)
SCK/2.2D: U1.P$A12 (P0.02/AIN0)
SCL/2.4C: IC1.B1 (SCL), IC3.12 (SCX), R4.1, R17.2, TP_SCL.TP, U1.P$M2 (P0.07)
SDA/2.4C: IC1.C1 (SDA), IC3.2 (SDX), R2.1, R18.2, TP_SDA.TP, U1.P$L1 (P0.06)
SWDCLK: J2.4, TP_SWDCLK.TP, U1.P$AA24 (SWDCLK)
SWDIO: J2.2, TP_SWDIO.TP, U1.P$AC24 (SWDIO)
SWO: TP_SWO.TP, U1.P$AD22 (P1.00)
VBAT/2.5C: C37.2, IC1.C2 (BAT)
VBUS/2.6D: C21.1, C38.2, IC1.A2 (IN), U1.P$AD2 (VBUS)
VREG: C23.2, C24.2, C39.1, IC1.B2 (SYS), IC9.A1 (EN), IC9.A2 (VIN_1), IC9.A3 (VIN_2), TP_VREG.TP

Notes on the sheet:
LiPo Charger
DC/DC
IMU
SWD
MCU, Power, IMU, SWD
drawn by: Ana Lupu
N.C.
DEC1
DEC3
DEC4_6

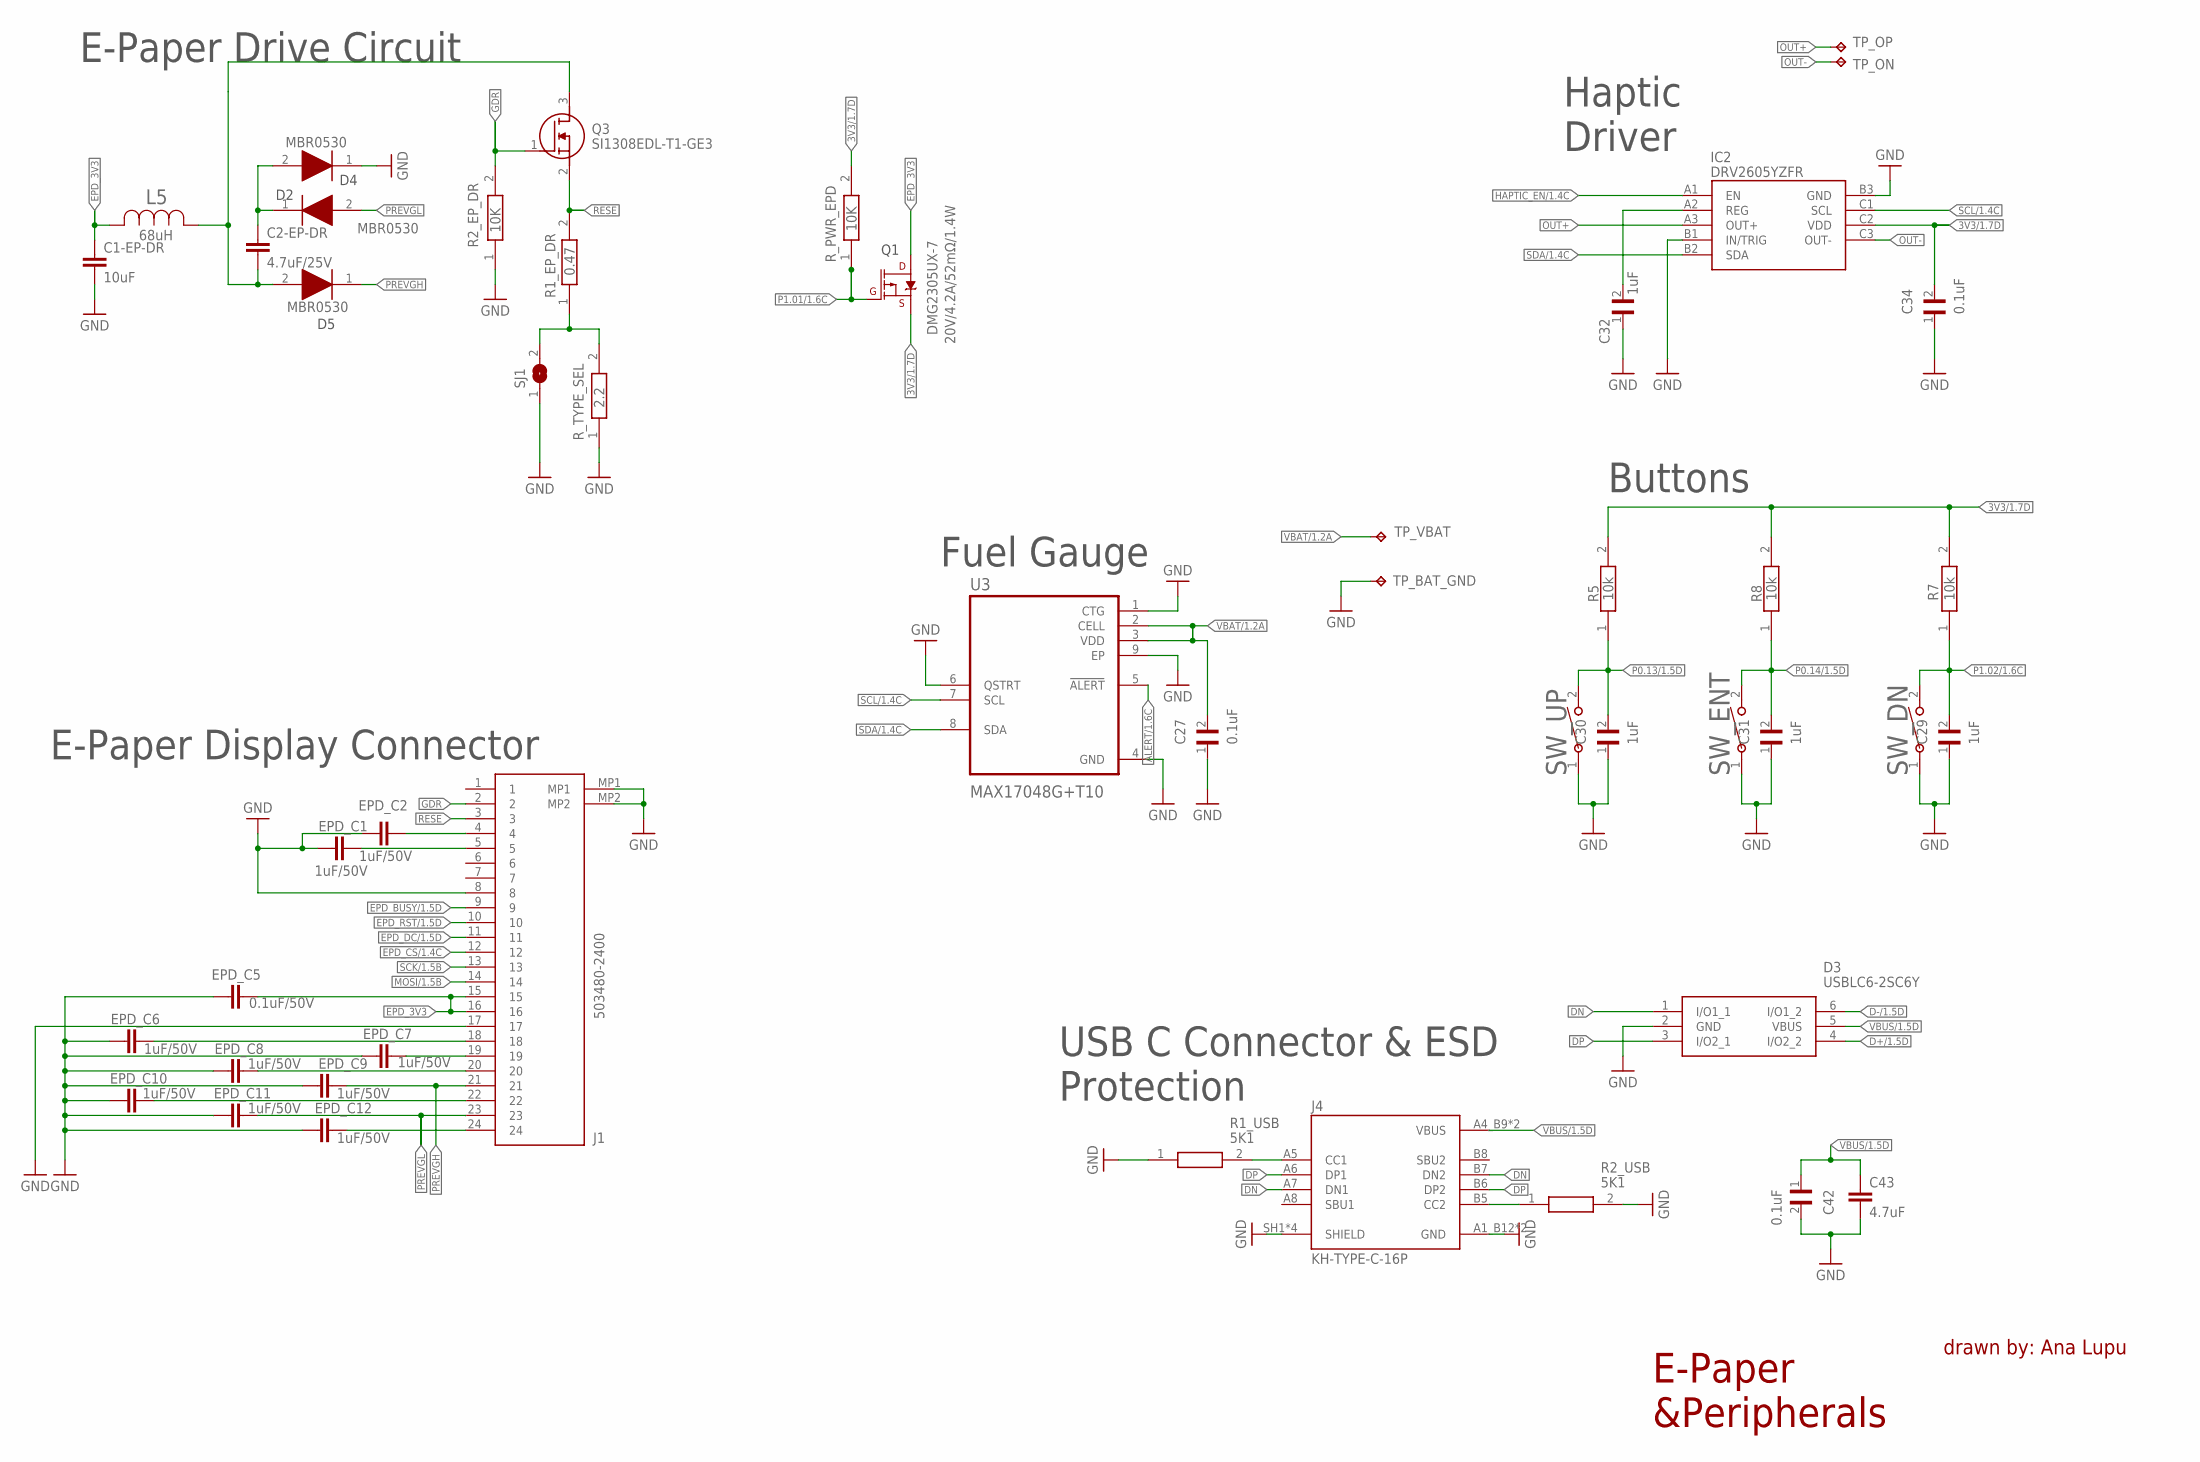
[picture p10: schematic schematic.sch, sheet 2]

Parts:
C1-EP-DR: 10uF; PERFECT_0402_0402
C2-EP-DR: 4.7uF/25V; PERFECT_0402_0402
C27, C34, C42: 0.1uF; GRM011R60J152KE01L_2_CAPC0201X13N
C29, C30, C31, C32: 1uF; GRM011R60J152KE01L_2_CAPC0201X13N
C43: 4.7uF; PERFECT_0402_0402
D2, D4, D5: MBR0530; ESP32_C6_LIBRARY_5_SOD3716X135N
D3: USBLC6-2SC6Y; ESP32_C6_LIBRARY_3_SOT95P280X145-6N
DMG2305UX-7: 20V/4.2A/52mΩ/1.4W; ESP32_C6_LIBRARY_4_ESP32_C6_LIBRARY_4_ESP32_C6_LIBRARY_4_ES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
EPD_C1, EPD_C2, EPD_C6, EPD_C7, EPD_C8, EPD_C9, EPD_C10, EPD_C11, EPD_C12: 1uF/50V; PERFECT_0402_0402
EPD_C5: 0.1uF/50V; NORDIC_NRF_3_RESC0201_L
IC2: DRV2605YZFR; DRV2605YZFR_BGA9C50P3X3_144X144X62
J1: 503480-2400; 503480-2400_5034802400
J4: KH-TYPE-C-16P; KH-TYPE-C-16P_KINGHELM_KH-TYPE-C-16P
L5: 68uH; ESP32_C6_LIBRARY_2_IND_4828-WE-TPC_WRE
Q3: SI1308EDL-T1-GE3; ESP32_C6_LIBRARY_6_SOT65P210X110-3N
R1_EP_DR: 0.47; ERA-1AEB3401C_0201
R1_USB, R2_USB: 5K1; ERA-1AEB3401C_0201
R2_EP_DR: 10K; ERA-1AEB3401C_0201
R5, R7, R8: 10k; ERA-1AEB3401C_0201
R_PWR_EPD: 10K; ERA-1AEB3401C_0201
R_TYPE_SEL: 2.2; ERA-1AEB3401C_0201
SJ1: ESP32_C6_LIBRARY_7_JUMPER_SJ
SW_DN: 2025-10-22_07-23-44_LIBRARY_EVP-AKE31ASW_EVP-AKE3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; 2025-10-22_07-23-44_LIBRARY_SW_EVP-AKE31A_PAN
SW_ENT: 2025-10-22_07-23-44_LIBRARY_EVP-AKE31ASW_EVP-AKE3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; 2025-10-22_07-23-44_LIBRARY_SW_EVP-AKE31A_PAN
SW_UP: 2025-10-22_07-23-44_LIBRARY_EVP-AKE31ASW_EVP-AKE3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; 2025-10-22_07-23-44_LIBRARY_SW_EVP-AKE31A_PAN
TP_BAT_GND: HECTOR_WATCH_1_TPTP20R; HECTOR_WATCH_1_TP20R
TP_ON: HECTOR_WATCH_1_TPTP20R; HECTOR_WATCH_1_TP20R
TP_OP: HECTOR_WATCH_1_TPTP20R; HECTOR_WATCH_1_TP20R
TP_VBAT: HECTOR_WATCH_1_TPTP20R; HECTOR_WATCH_1_TP20R
U3: MAX17048G+T10; ESP32_C6_LIBRARY_SON50P200X200X80-9N

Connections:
3V3/1.7D: C34.2, DMG2305UX-7.2 (S), IC2.C2 (VDD), R5.2, R7.2, R8.2, R_PWR_EPD.2
ALERT/1.6C: U3.5 (!ALERT)
D+/1.5D: D3.4 (I/O2_2)
D-/1.5D: D3.6 (I/O1_2)
DN: D3.1 (I/O1_1), J4.A7 (DN1), J4.B7 (DN2)
DP: D3.3 (I/O2_1), J4.A6 (DP1), J4.B6 (DP2)
EPD_3V3: C1-EP-DR.1, DMG2305UX-7.3 (D), EPD_C5.2, J1.15, J1.16, L5.2
EPD_BUSY/1.5D: J1.9
EPD_CS/1.4C: J1.12
EPD_DC/1.5D: J1.11
EPD_RST/1.5D: J1.10
GDR: J1.2, Q3.1 (G), R2_EP_DR.2
GND: C1-EP-DR.2, C27.1, C29.1, C30.1, C31.1, C32.1, C34.1, C42.2, C43.2, D3.2 (GND), D4.1 (K), EPD_C1.1, EPD_C2.1, EPD_C5.1, EPD_C6.1, EPD_C7.1, EPD_C8.1, EPD_C9.1, EPD_C10.1, EPD_C11.1, EPD_C12.1, IC2.B1 (IN/TRIG), IC2.B3 (GND), J1.8, J1.17, J1.MP1, J1.MP2, J4.A1_B12 (GND), J4.A12_B1 (GND), J4.SH1 (SHIELD), J4.SH2 (SHIELD), J4.SH3 (SHIELD), J4.SH4 (SHIELD), R1_USB.1, R2_EP_DR.1, R2_USB.2, R_TYPE_SEL.1, SJ1.1, SW_DN.1, SW_ENT.1, SW_UP.1, TP_BAT_GND.TP, U3.1 (CTG), U3.4 (GND), U3.6 (QSTRT), U3.9 (EP); also elsewhere on the board
HAPTIC_EN/1.4C: IC2.A1 (EN)
MOSI/1.5B: J1.14
unnamed: C2-EP-DR.2, D5.2 (A), L5.1, Q3.3 (D)
unnamed: C2-EP-DR.1, D2.1 (K), D4.2 (A)
unnamed: EPD_C2.2, J1.4
unnamed: R1_EP_DR.1, R_TYPE_SEL.2, SJ1.2
unnamed: EPD_C1.2, J1.5
unnamed: EPD_C6.2, J1.18
unnamed: EPD_C7.2, J1.19
unnamed: EPD_C8.2, J1.20
unnamed: J4.A5 (CC1), R1_USB.2
unnamed: EPD_C10.2, J1.22
unnamed: C32.2, IC2.A2 (REG)
unnamed: EPD_C12.2, J1.24
unnamed: J4.B5 (CC2), R2_USB.1
OUT+: IC2.A3 (OUT+), TP_OP.TP
OUT-: IC2.C3 (OUT-), TP_ON.TP
P0.13/1.5D: C30.2, R5.1, SW_UP.2
P0.14/1.5D: C31.2, R8.1, SW_ENT.2
P1.01/1.6C: DMG2305UX-7.1 (G), R_PWR_EPD.1
P1.02/1.6C: C29.2, R7.1, SW_DN.2
PREVGH: D5.1 (K), EPD_C9.2, J1.21
PREVGL: D2.2 (A), EPD_C11.2, J1.23
RESE: J1.3, Q3.2 (S), R1_EP_DR.2
SCK/1.5B: J1.13
SCL/1.4C: IC2.C1 (SCL), U3.7 (SCL)
SDA/1.4C: IC2.B2 (SDA), U3.8 (SDA)
VBAT/1.2A: C27.2, TP_VBAT.TP, U3.2 (CELL), U3.3 (VDD)
VBUS/1.5D: C42.1, C43.1, D3.5 (VBUS), J4.A4_B9 (VBUS), J4.A9_B4 (VBUS)

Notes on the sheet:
E-Paper Drive Circuit
Haptic Driver
E-Paper Display Connector
Fuel Gauge
Buttons
USB C Connector & ESD Protection
E-Paper &Peripherals
drawn by: Ana Lupu

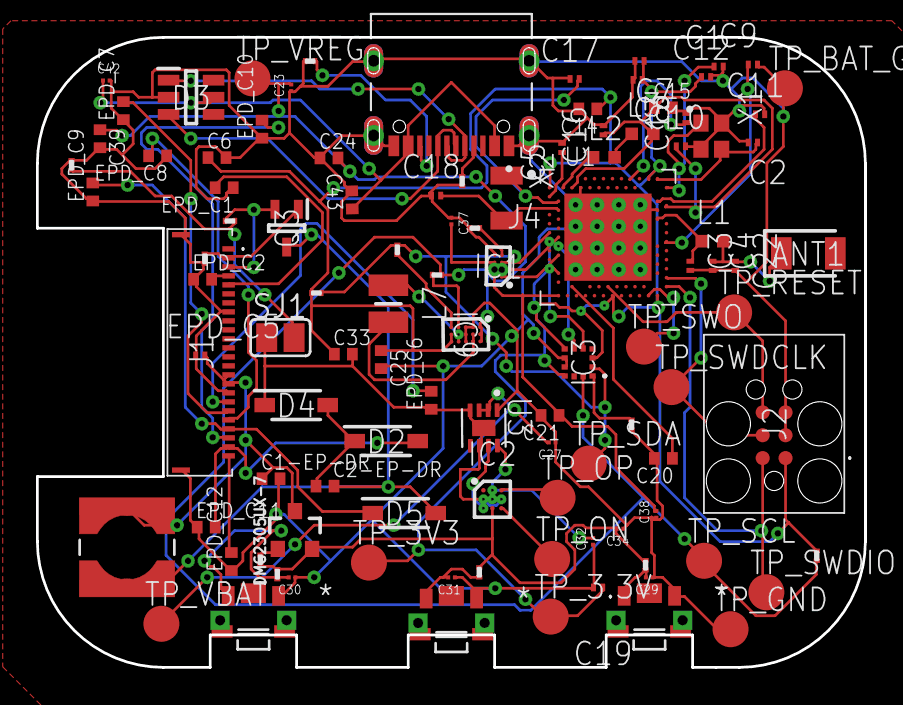
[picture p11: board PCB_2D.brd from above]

Board: 2 copper layers, 46.0 x 35.0 mm, 105 parts (0 on the bottom side), 65 nets.

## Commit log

2026-04-10 Schematic and parts of PCB
    [PCB.brd, schematic.sch]
2026-04-22 Revise README with project details and hardware overview
    Updated project title, added detailed project description, and expanded sections on hardware components, power management, and PCB layout.

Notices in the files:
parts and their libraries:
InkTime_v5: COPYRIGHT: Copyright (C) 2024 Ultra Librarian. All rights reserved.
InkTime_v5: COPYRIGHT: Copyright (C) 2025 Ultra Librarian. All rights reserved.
